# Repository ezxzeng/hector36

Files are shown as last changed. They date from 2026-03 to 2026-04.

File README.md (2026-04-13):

# Hector36
## A sub-100×100 mm split keyboard inspired by Totem, without the extra pinky key

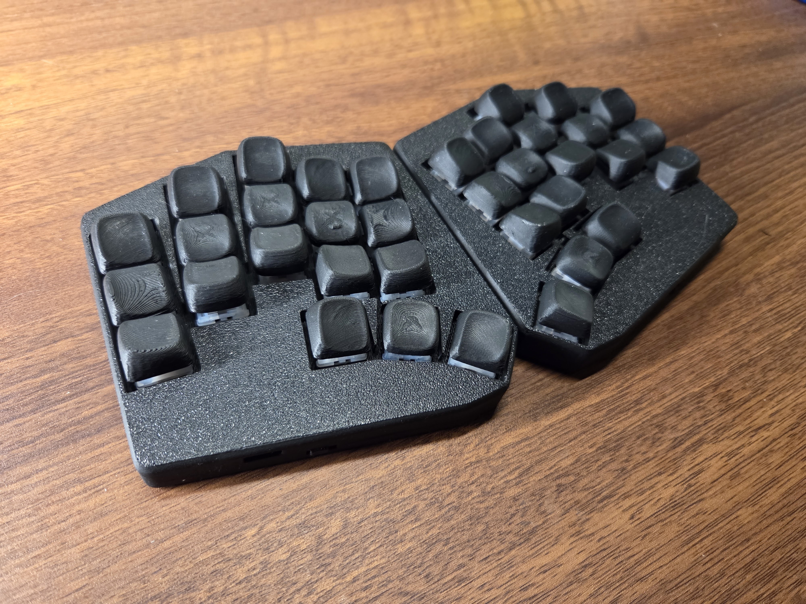
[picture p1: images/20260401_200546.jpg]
Hector36 assembled


left | right | outline
-|-|-
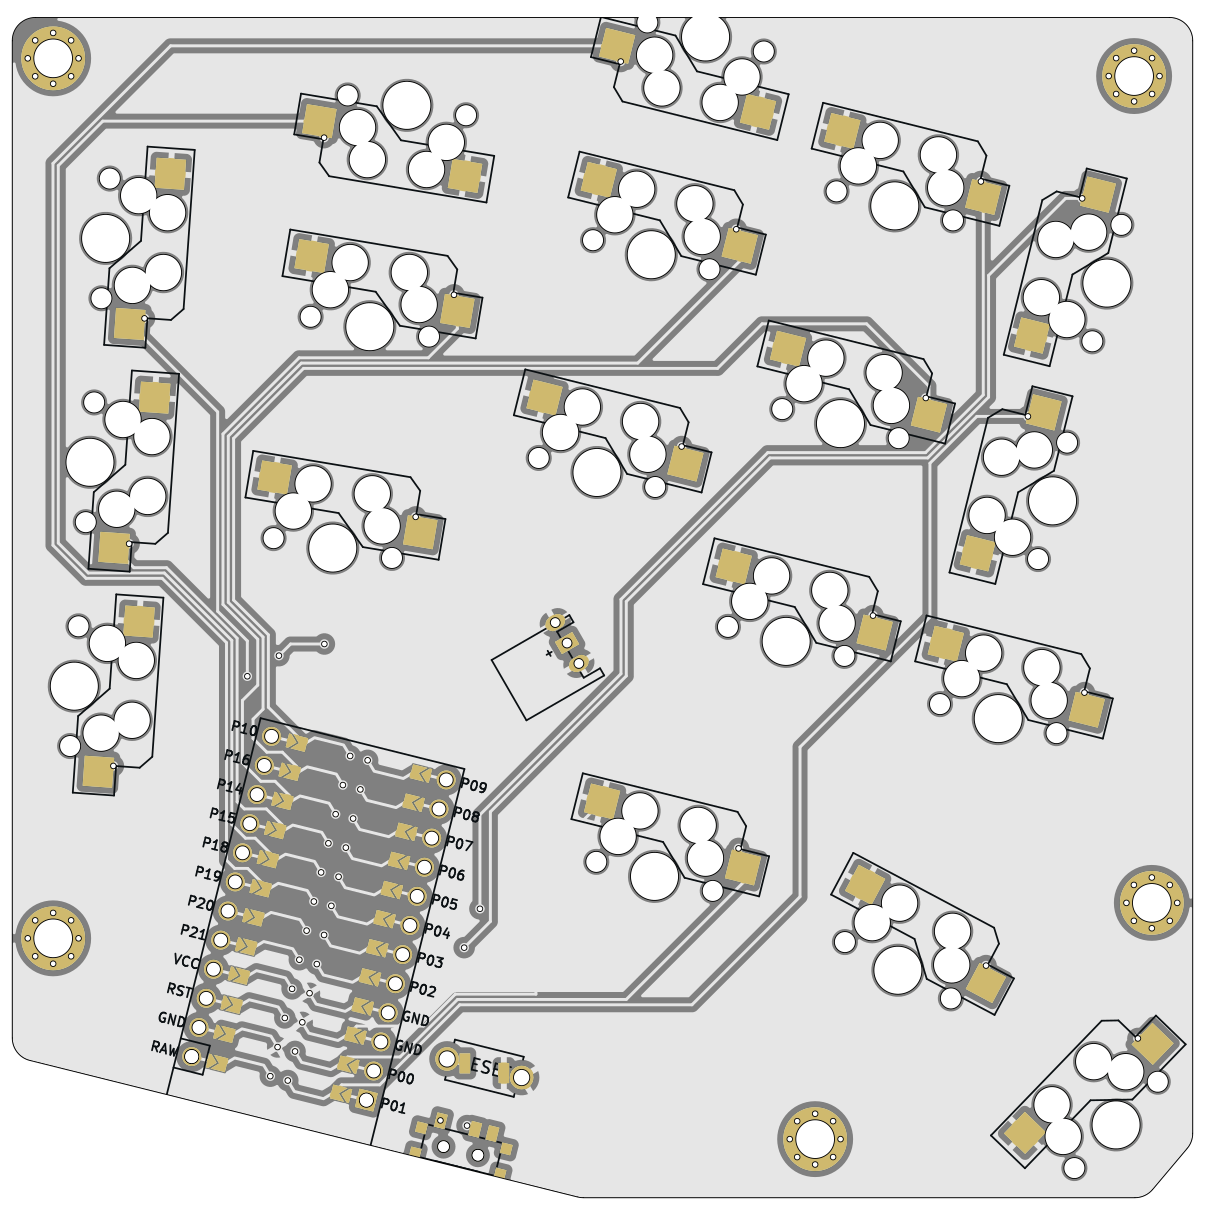
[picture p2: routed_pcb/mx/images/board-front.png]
left
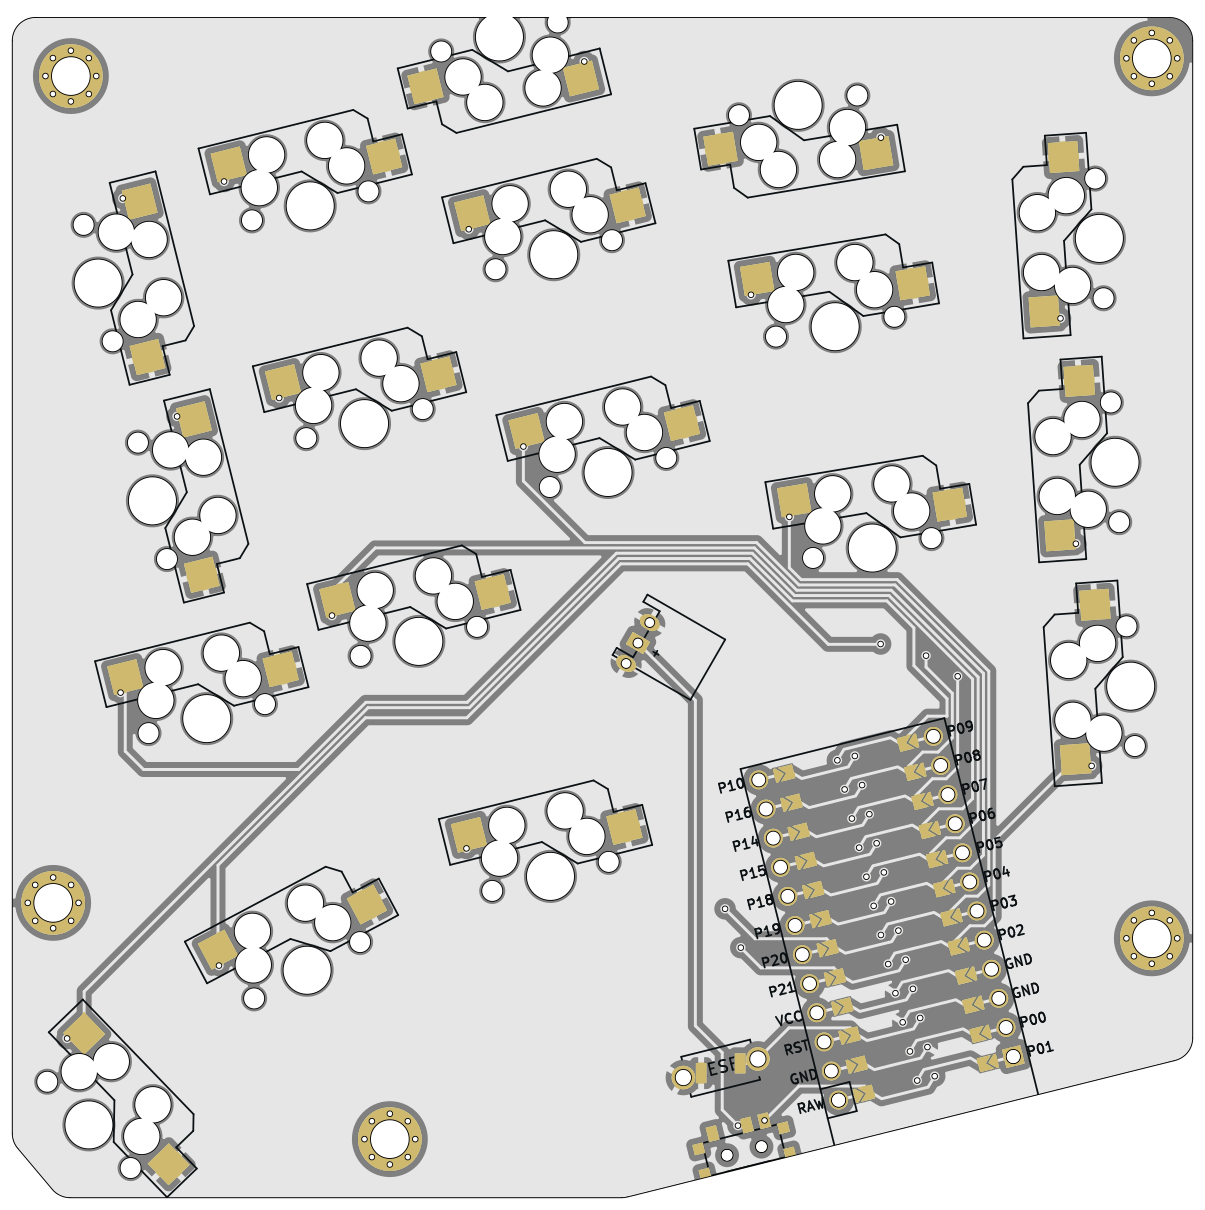
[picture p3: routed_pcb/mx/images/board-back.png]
right
 |  | outline

Hector36 is a 36-key split keyboard with a 5×3 layout and 3 thumb keys per half.  
It is designed to stay under **100 mm × 100 mm per PCB**, which makes fabrication much cheaper while still keeping a comfortable, aggressively staggered and splayed layout.

## Features
- Sub-100×100 mm PCB for low fabrication cost
- Split 36-key layout with 3 thumb keys per half
- Reversible PCB
- Diode-less design
- Programmatically generated with Ergogen
- hotswap sockets

## PCB variants

This repo currently contains several board variants:

| Version | Status | Folder | Buildguide |
|---|---|---|---|
| MX | Tested and working | [`routed_pcb/mx`](routed_pcb/mx) | [guide](routed_pcb/mx/README.md#Build-Guide)
| Choc with choc spacing | Fabricated, not yet received or tested | [`routed_pcb/choc_spacing`](routed_pcb/choc_spacing) | tbd
| Choc with mx spacing | Not routed | `routed_pcb/choc` | tbd
| Gateron low profile with mx spacing | Not routed | `routed_pcb/gateron_lp` | tbd

For PCB fabrication through JLCPCB or PCBWay, use the gerbers.zip file inside the corresponding version folder.

## Components

| Part | Qty | Estimated price | Notes |
| --- | --: | ---: | --- |
| PCB | 2 | $3.50 for 5 | |
| nice!nano or nRF52840 | 2 | $4 each for nRF52840 |  I'm using nRF52840 for cheaper cost |
| Reset switch | 2 | $3.40 for 100 | 3×6×2.5 mm, 2-pin, SMD push button |
| Power switch | 2 | $4 for 100 | 7-pin, MSK 12C02 |
| Battery | 2 | $15 for 2 | 301230, 3.7 V Li-Po |
| 2P ST PH2.0 right-angle socket | 2 | $2 for 100 | Optional |
| Hotswap socket |  36 | $10 for 70 | also depends on socket type |
| Switch |  36 | — | |
| Keycap |  36 | — | Some keycaps may need rotated orientation for the Choc version. |
| M3 heat-set insert | 8 | $3 for 50 | |
| M3 screw | 8 | $3 for 50 | |
| Rubber feet | 8 | $5 for 50 | |

note that estimated price is from a brief look at aliexpress, and might be higher than what you'll actually have to pay if you buy in higher quantities (especially for batteries)

optional: [socketing the controller](https://docs.splitkb.com/frequently-asked-questions/about-split-keyboards/microcontrollers/sockets), see [this guide](https://www.40percent.club/p/socketing-pro-micro.html) or [this guide](https://docs.splitkb.com/product-guides/aurora-series/build-guide/microcontrollers)

## Firmware
see [zmk module](https://github.com/ezxzeng/zmk-keyboards-hector36)

## Inspiration

- [bgkeeb](https://github.com/sadekbaroudi/bgkeeb)
  - keyboard pcbs under 100mm x 100mm are cheap
- [cheapis](https://github.com/dotleon/cheapis) 
  - sweeps can be rotated for more room and length between the thumb cluster and rest of the keys and still fit within 100mm x 100mm
- [samoklava](https://github.com/soundmonster/samoklava) and [ergogen](https://ergogen.cache.works/) to get keyboard layouts programatically 
- [sweep](https://github.com/davidphilipbarr/Sweep) and [swweeep](https://github.com/sadekbaroudi/sweep36) for form factor and diode-less design
- [totem](https://github.com/GEIGEIGEIST/totem) and [KLOR](https://github.com/GEIGEIGEIST/KLOR)
  - keys layout
  - sandwich case looks really slick and clean, and can also hide the controller parts that will be located under the palm

## Other considerations
- this design does not support LEDs or displays
- [samoklava's](https://github.com/soundmonster/samoklava) auto routing does not really work here
- some keycaps might need to be rotated 90 degrees

## Rendering and generation

### Ergogen:
```bash
ergogen .
```
### Case:
printables: https://www.printables.com/model/1659997-case-for-hector36

onshape [link](https://cad.onshape.com/documents/dab7ead69061981322a5fa82/w/eeec2b07408bf6c3576b55db/e/49101eb28d1b1828dfaa91ca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)

### Get board image renderings:
```bash
export pcb_type="mx"

docker run -v $(pwd):/kikit --entrypoint pcbdraw yaqwsx/kikit:v1.3.0-v7  plot --style style.json routed_pcb/$pcb_type/board.kicad_pcb routed_pcb/$pcb_type/images/board-front.png

docker run -v $(pwd):/kikit --entrypoint pcbdraw yaqwsx/kikit:v1.3.0-v7  plot --style style.json --side back routed_pcb/$pcb_type/board.kicad_pcb routed_pcb/$pcb_type/images/board-back.png
```

## Showcase



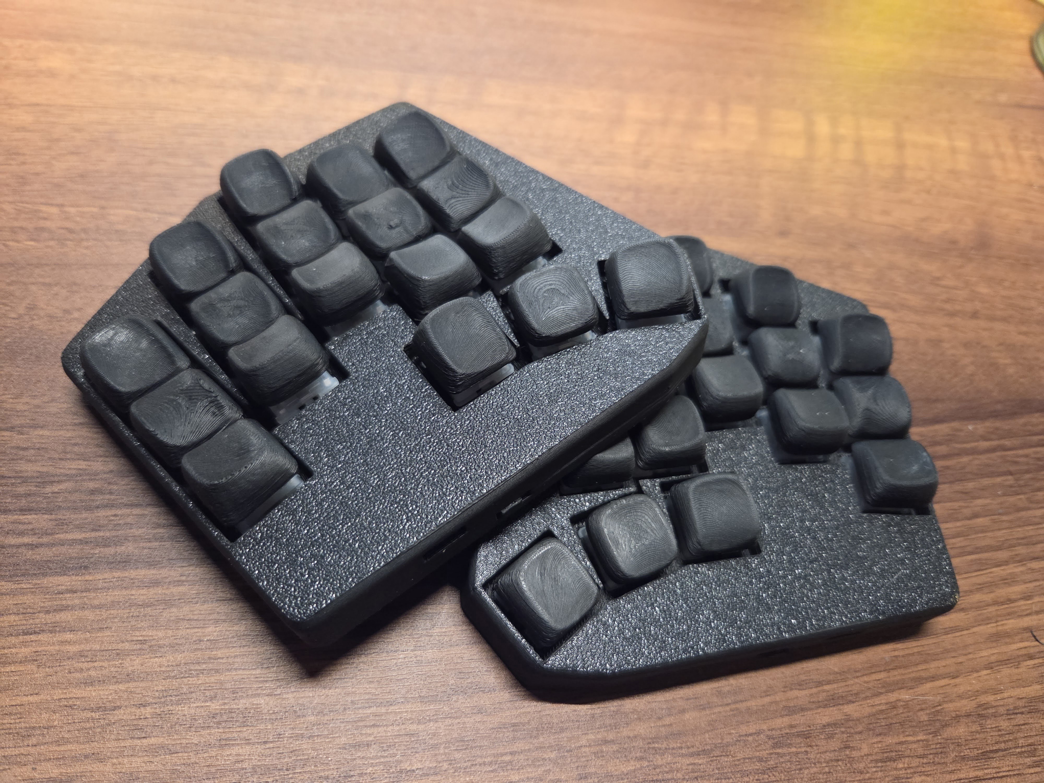
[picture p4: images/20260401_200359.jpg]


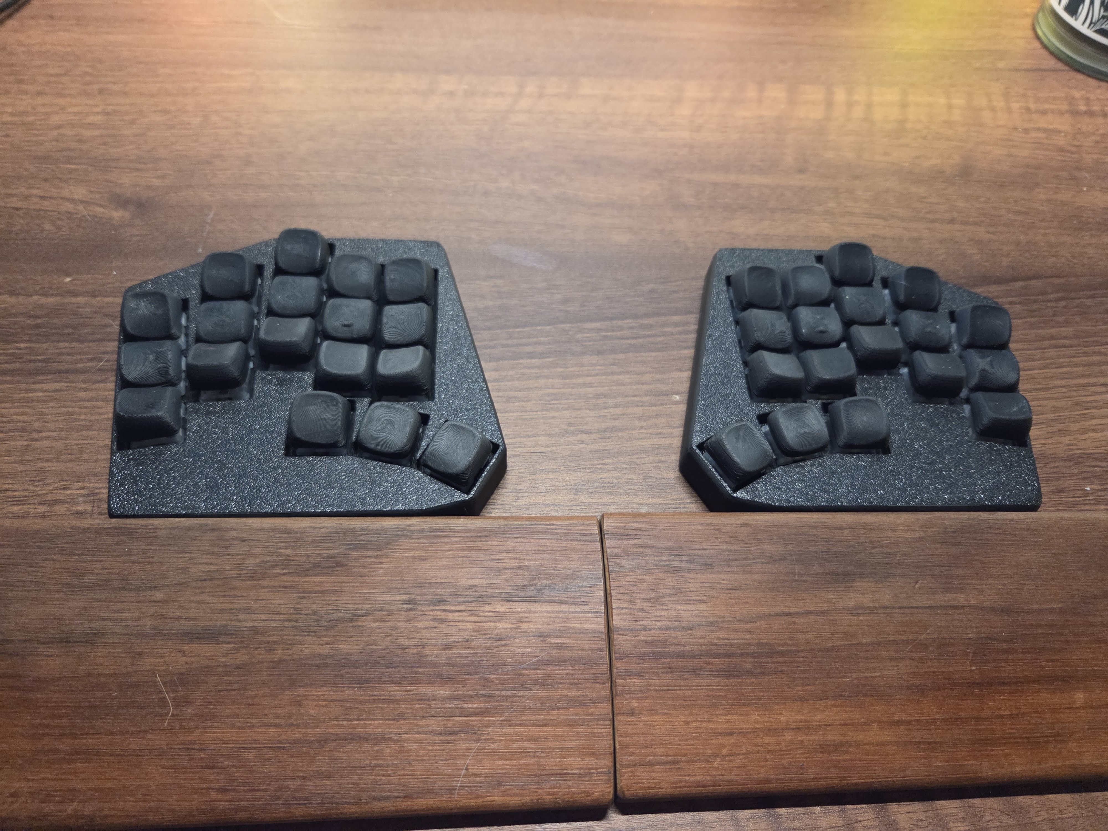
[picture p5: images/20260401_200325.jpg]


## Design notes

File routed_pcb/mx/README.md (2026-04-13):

left | right | outline
-|-|-
left | right | outline

# Build Guide

## 1. PCB
1. Take 2 pcbs and flip them to the **back** side
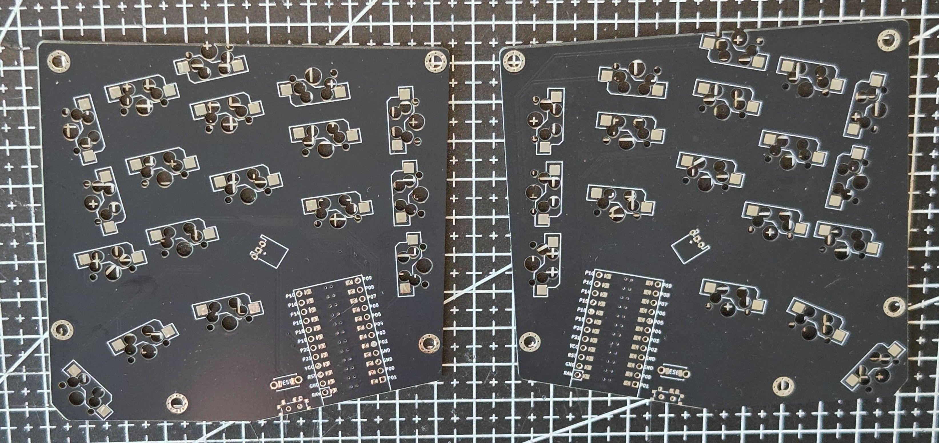
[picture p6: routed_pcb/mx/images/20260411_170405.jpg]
flip to back


1. Solder the jumper pads for the controller so that the two sides of the pads can be connected together.
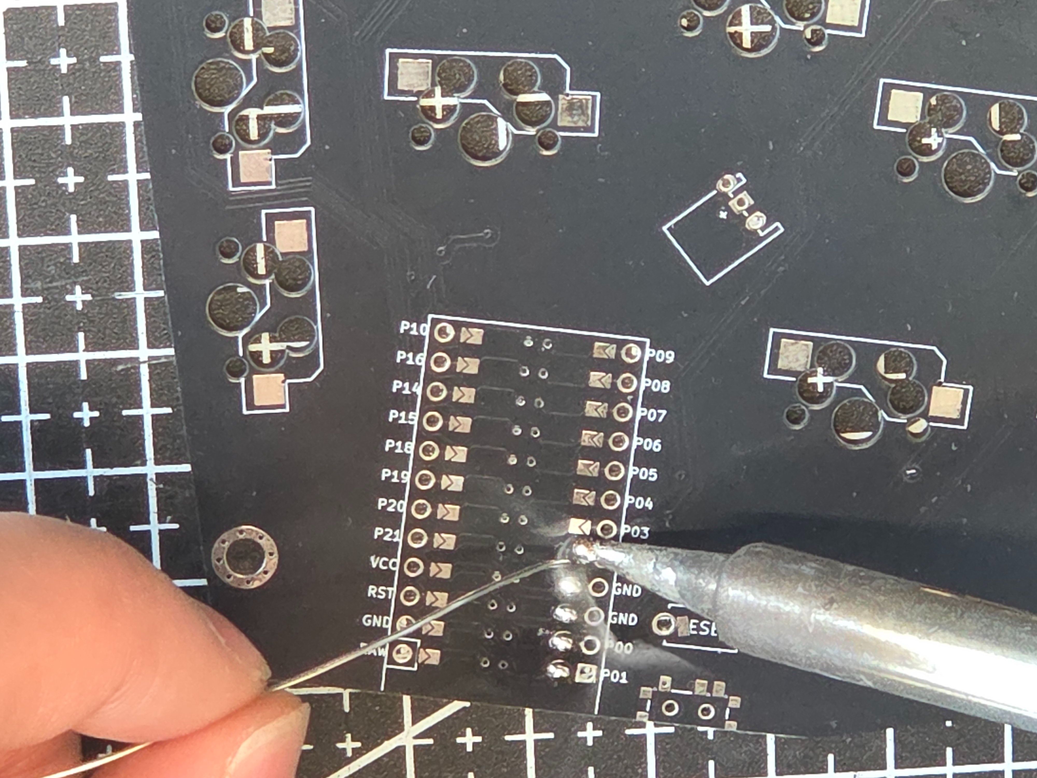
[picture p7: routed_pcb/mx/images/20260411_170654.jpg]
solder jumper pads


1. Still on the back side, put solder on the pads for the hotswap sockets
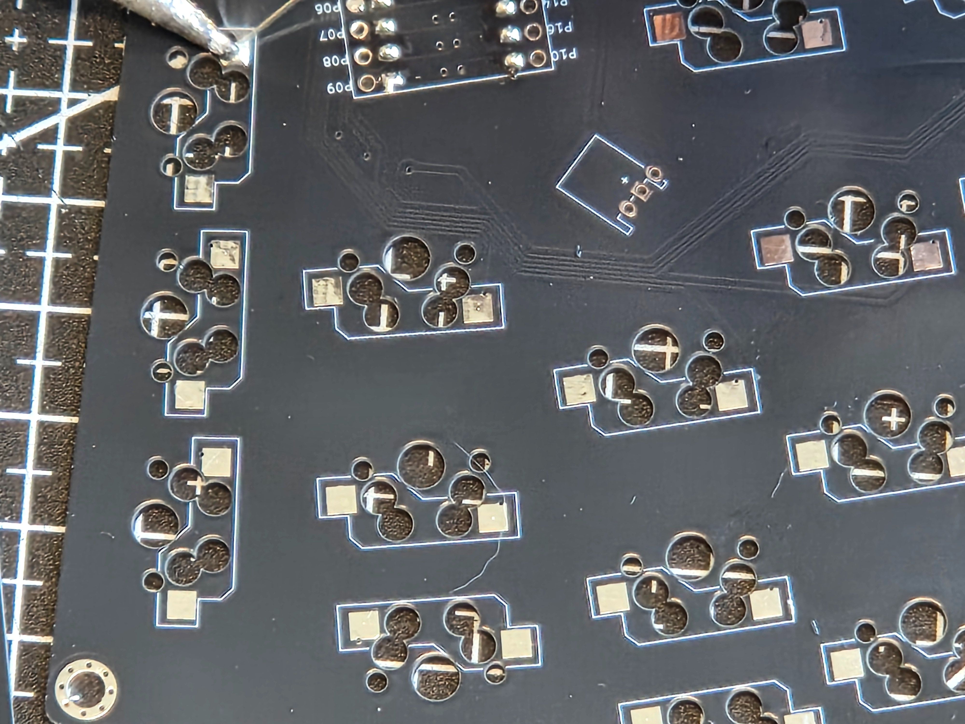
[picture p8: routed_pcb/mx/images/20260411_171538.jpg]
hotswap sockets


1. Melt the solder and press the hotswap sockets down, one side at a time. Use tweezers if that helps.
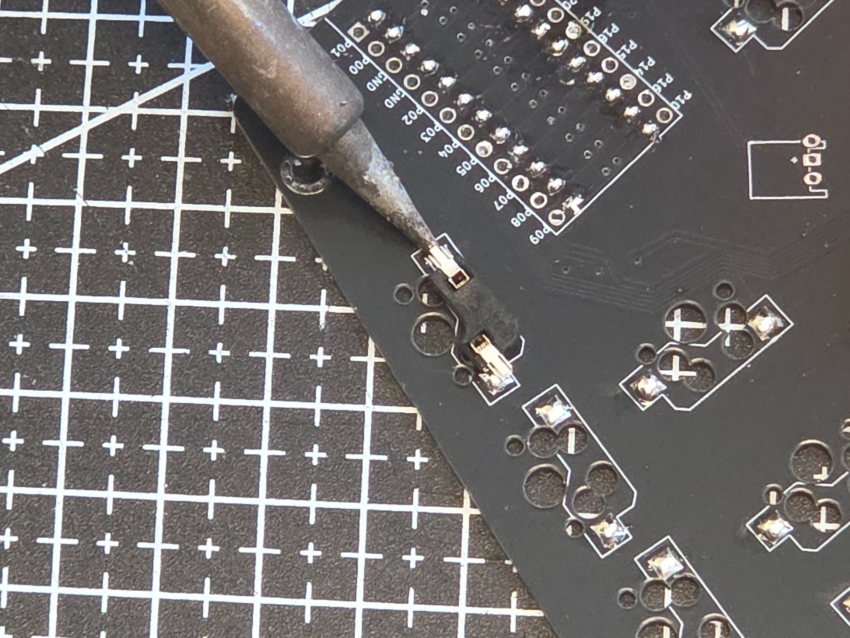
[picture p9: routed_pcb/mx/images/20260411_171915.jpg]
hotswap sockets 3


1. Still on the back side, put down the reset switch and solder it in. Depending on what switch you're using, it might help to bend the pins a bit down so it'll go inside the hole.
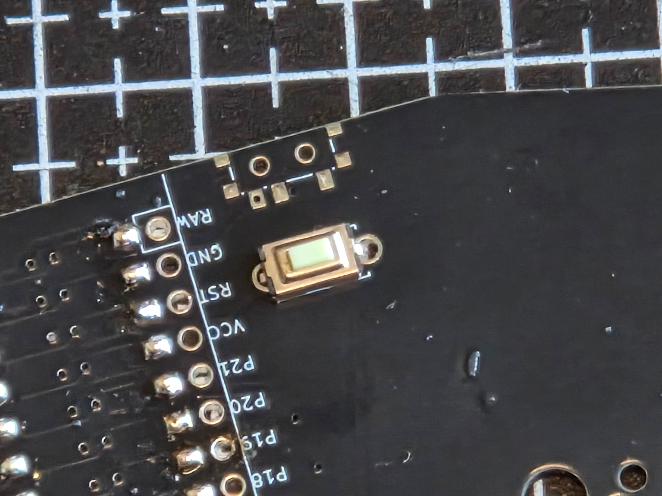
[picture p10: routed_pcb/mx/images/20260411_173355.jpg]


1. Flip over to the **front** side. Place the on/off switch and solder it in
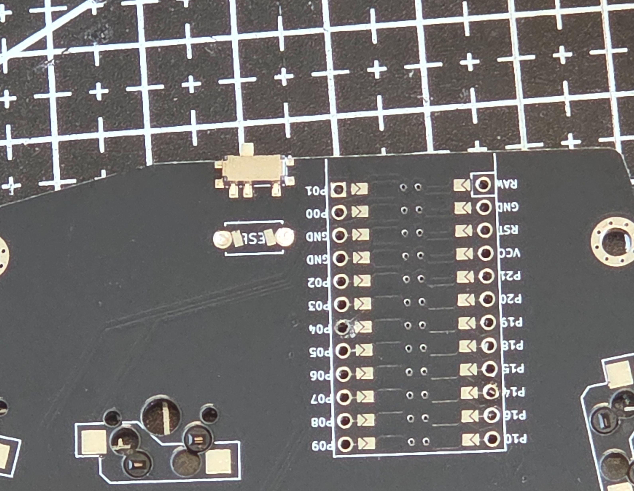
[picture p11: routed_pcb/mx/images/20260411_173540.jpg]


1. (Optional) align the JST connectors with the + sign. This may be different from the rectangle drawn on the pcb depending on where you order the right angle JST connectors from, or how the male connector on the battery looks. What's important is that the red wire aligns with the + sign. 
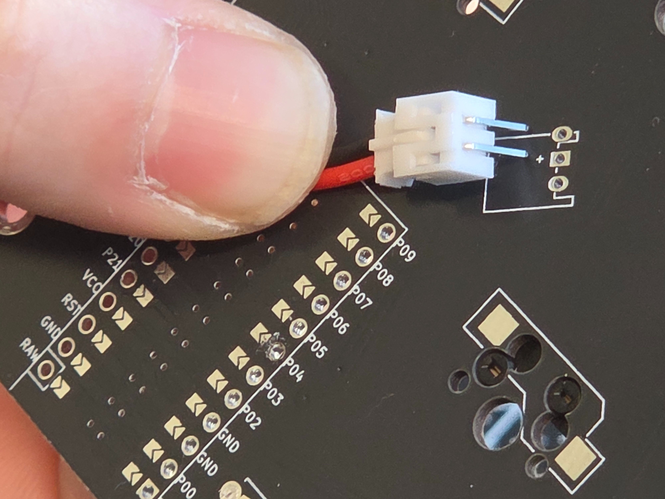
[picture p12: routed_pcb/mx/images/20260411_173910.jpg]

1. Solder the JST connector from the back. Alternatively, solder the battery wires directly.
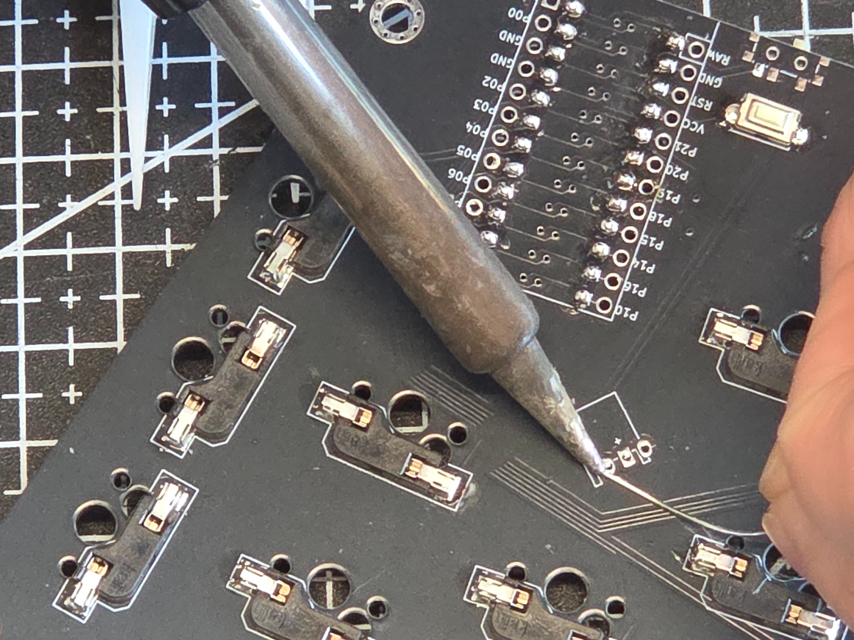
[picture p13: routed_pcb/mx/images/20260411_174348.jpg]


1. Back on the front side, place the controller **with the components side down**. The markings for which pin is what aligns on the **back** side, not the front. The two pins closest to the USBC port are **empty** and not used. Those are for Battery + and -, which are the same thing as RAW and GND.
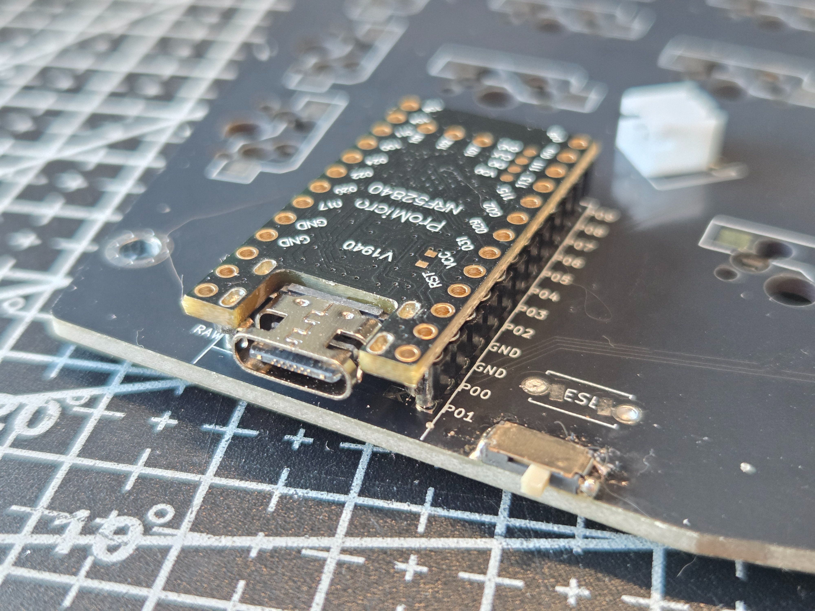
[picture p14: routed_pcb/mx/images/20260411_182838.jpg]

optionally, but highly recommended, follow [this](https://www.40percent.club/p/socketing-pro-micro.html) or [this alternative](https://docs.splitkb.com/product-guides/aurora-series/build-guide/microcontrollers) guide on how to socket the controller (see [here](https://docs.splitkb.com/frequently-asked-questions/about-split-keyboards/microcontrollers/sockets) for why you would want to).

1.  The finished PCB should look like this, with the battery slotted under the controller.
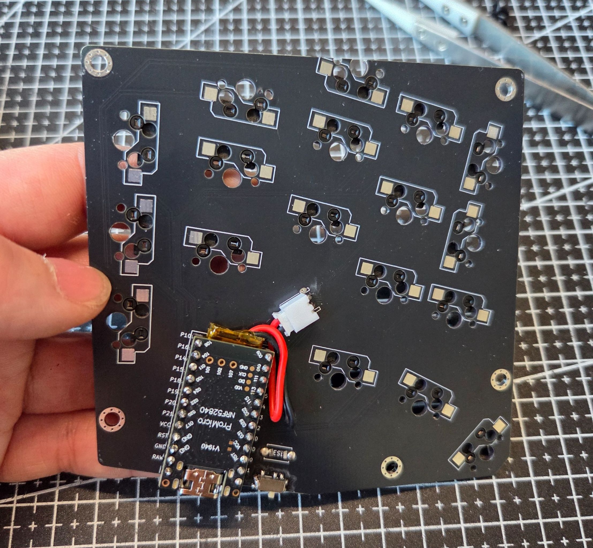
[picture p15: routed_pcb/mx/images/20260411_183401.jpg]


1.  Alternatively, if the battery does not fit under the controller, you can also put it on the side like this:
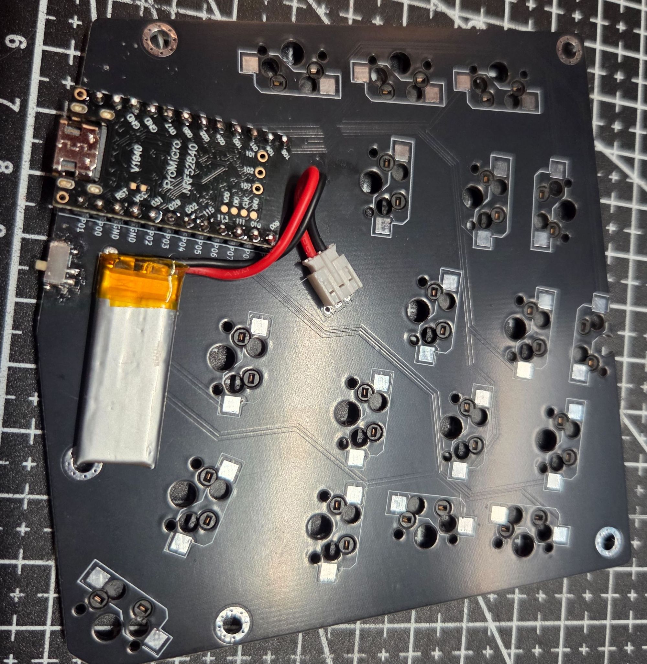
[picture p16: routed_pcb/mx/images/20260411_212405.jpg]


## 2. Case

Before printing, measure the distance from the top of the usbc port to the bottom of the pcb:
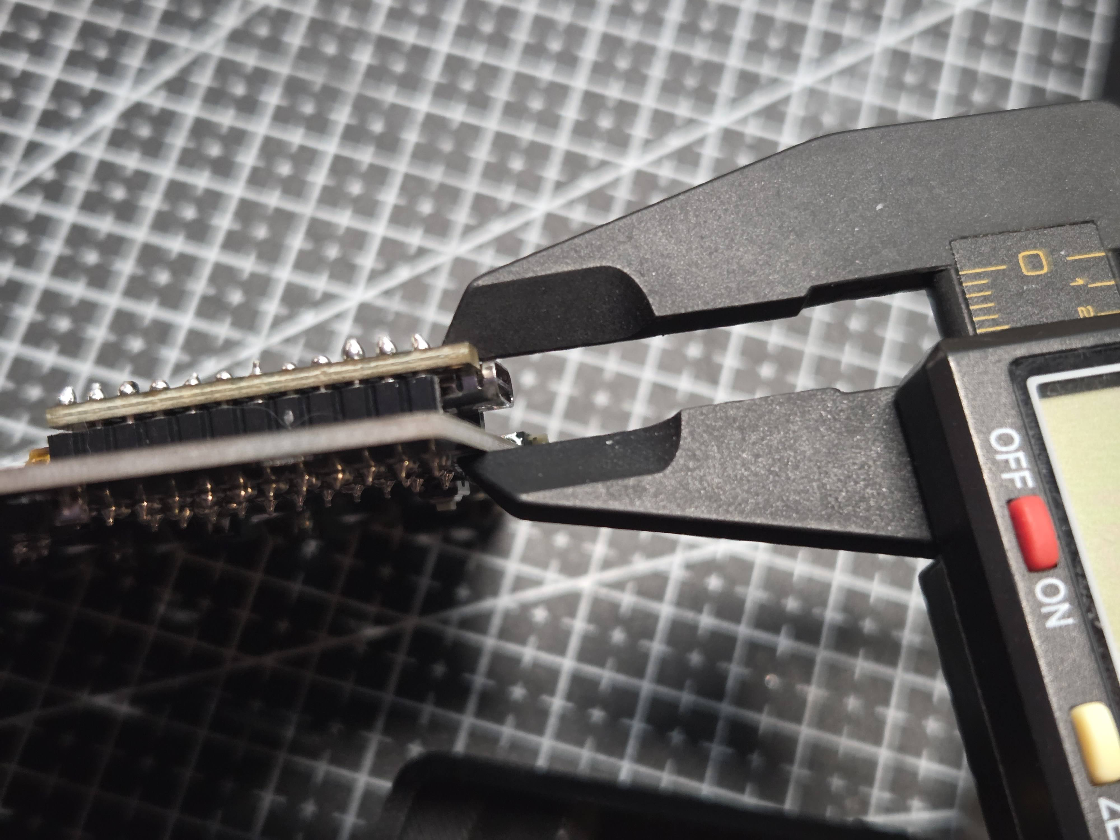
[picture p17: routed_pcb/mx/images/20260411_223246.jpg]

If this value is between 7.2mm and 8.2mm, then go ahead and use the STL files available on [printables](https://www.printables.com/model/1659997-case-for-hector36). Otherwise, you can copy and edit the [onshape file](https://cad.onshape.com/documents/dab7ead69061981322a5fa82/w/eeec2b07408bf6c3576b55db/e/49101eb28d1b1828dfaa91ca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). Simply modify the `bottom_pcb_to_usbc` variable at the top of the variable table.

1. Print the top half face down, and enable supports:
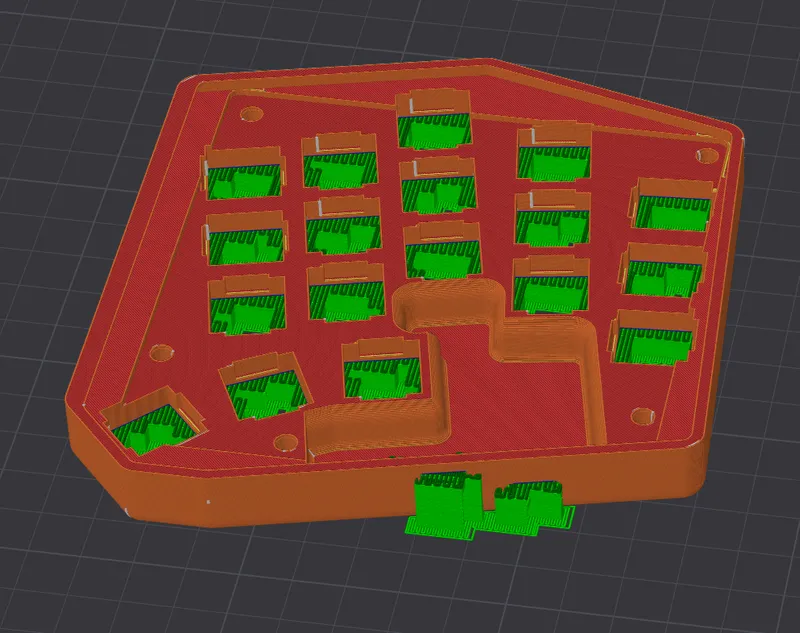
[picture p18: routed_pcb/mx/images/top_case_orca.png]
top_case_orca

1. disable support for the bottom part.
2. remove the support for the top half:
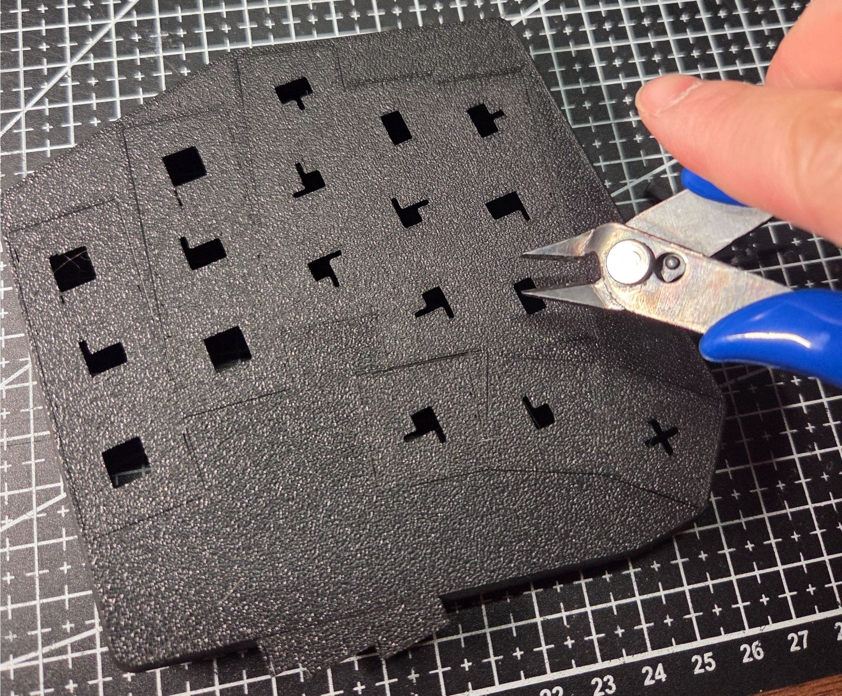
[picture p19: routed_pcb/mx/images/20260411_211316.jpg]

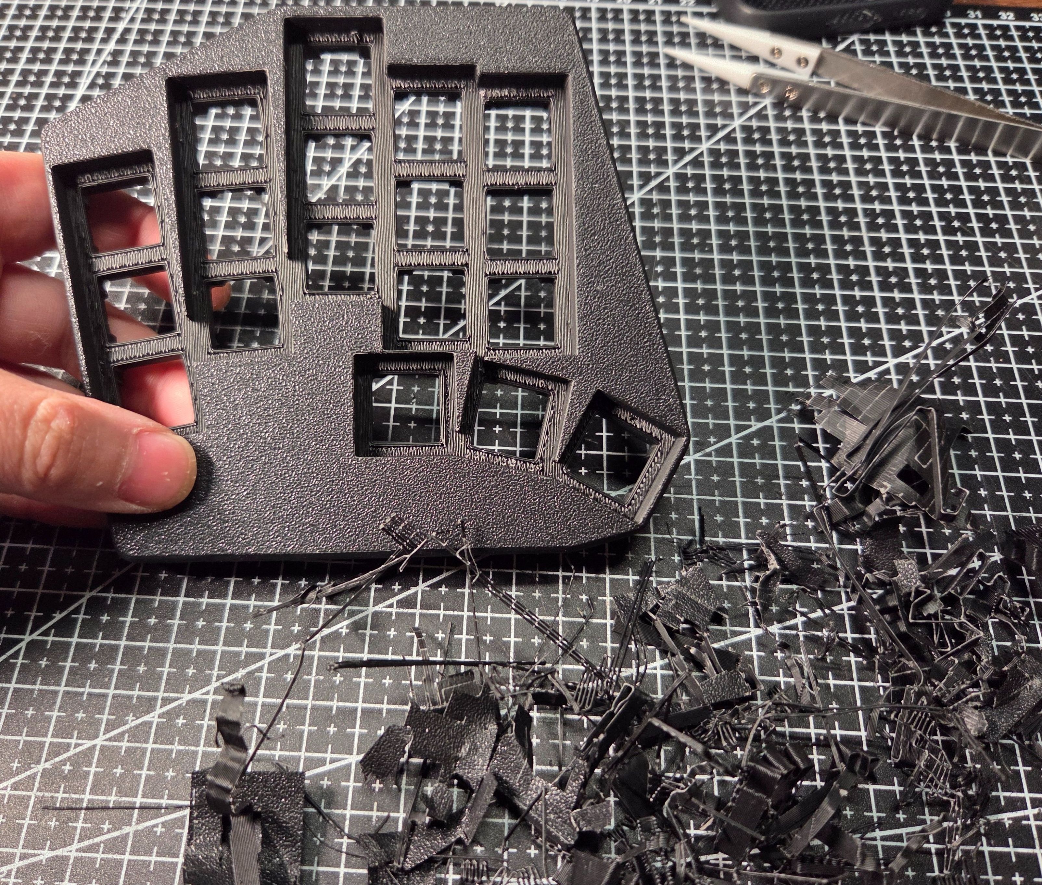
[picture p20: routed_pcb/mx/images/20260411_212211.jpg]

1. put in the M3 heat set inserts:
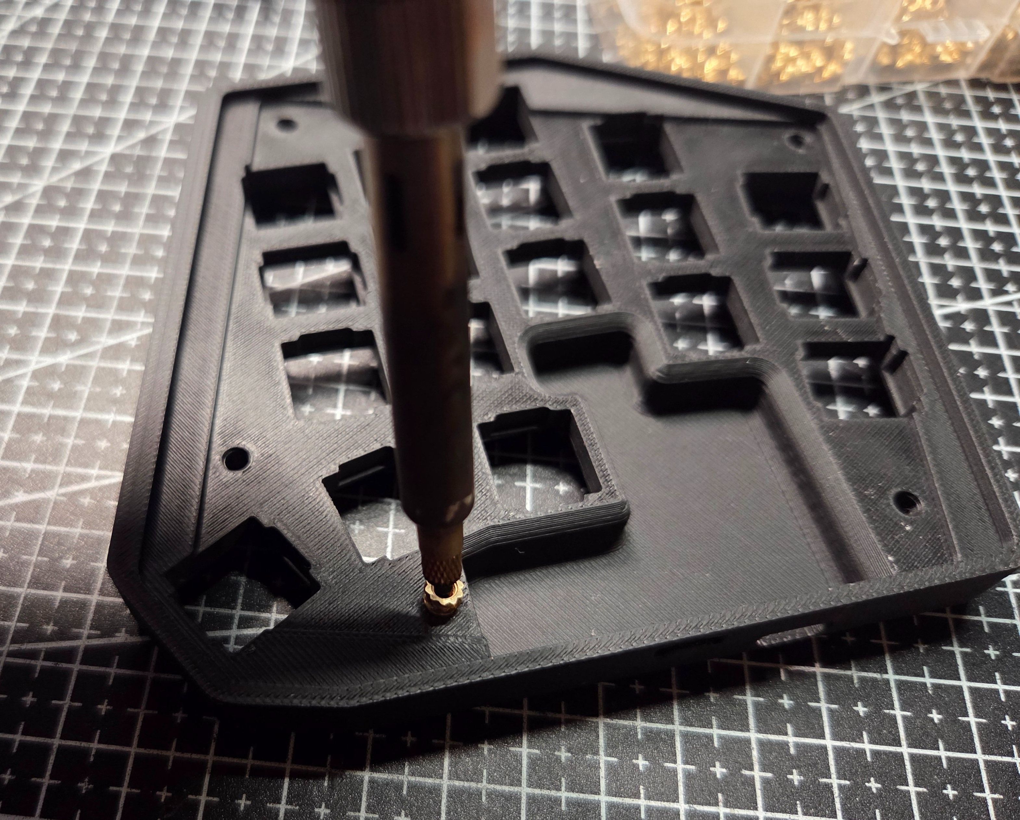
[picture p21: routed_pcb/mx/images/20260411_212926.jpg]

1. put in the switch extender in the orientation shown below
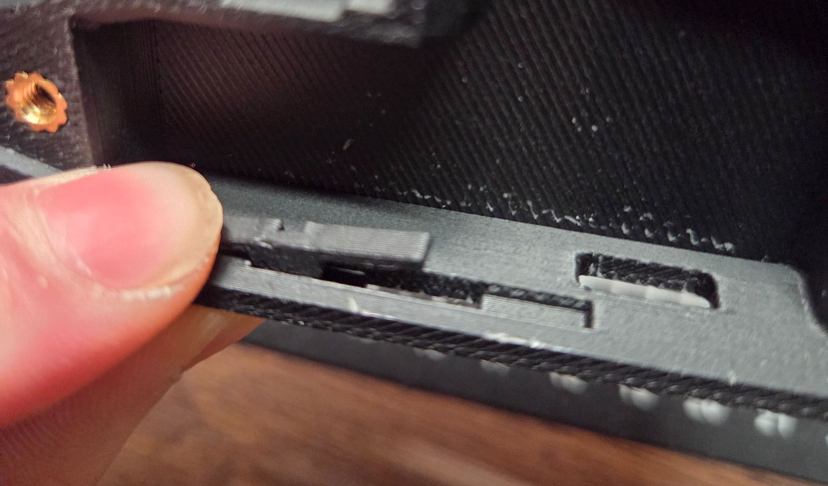
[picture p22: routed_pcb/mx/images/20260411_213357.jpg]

1. put everything together and we're done!
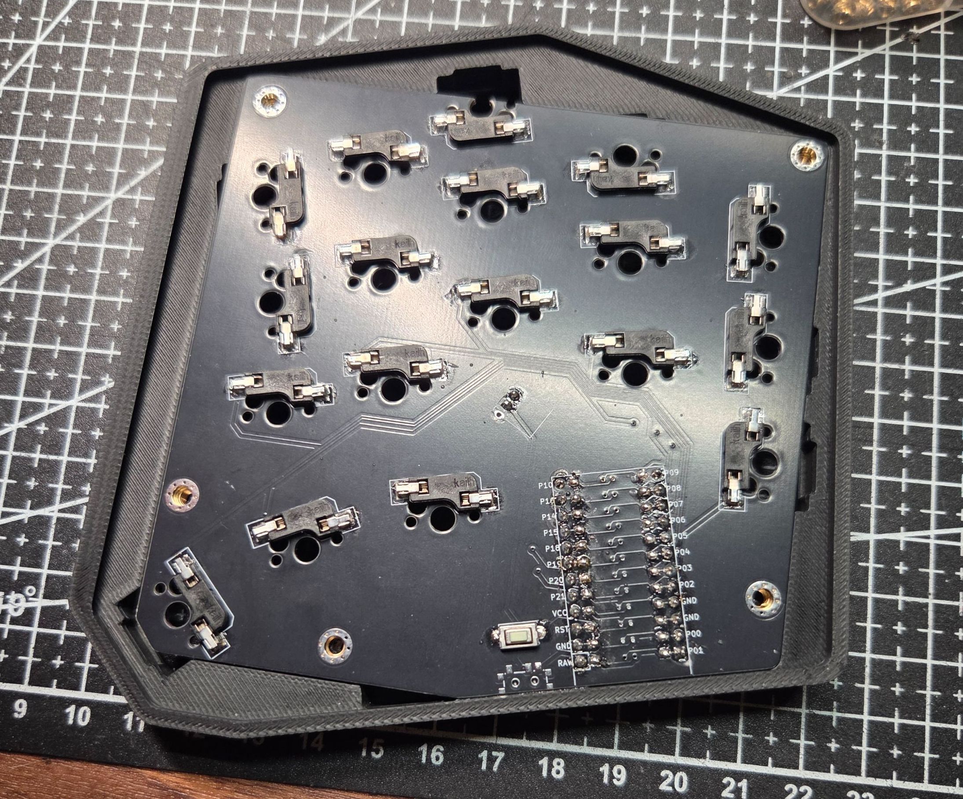
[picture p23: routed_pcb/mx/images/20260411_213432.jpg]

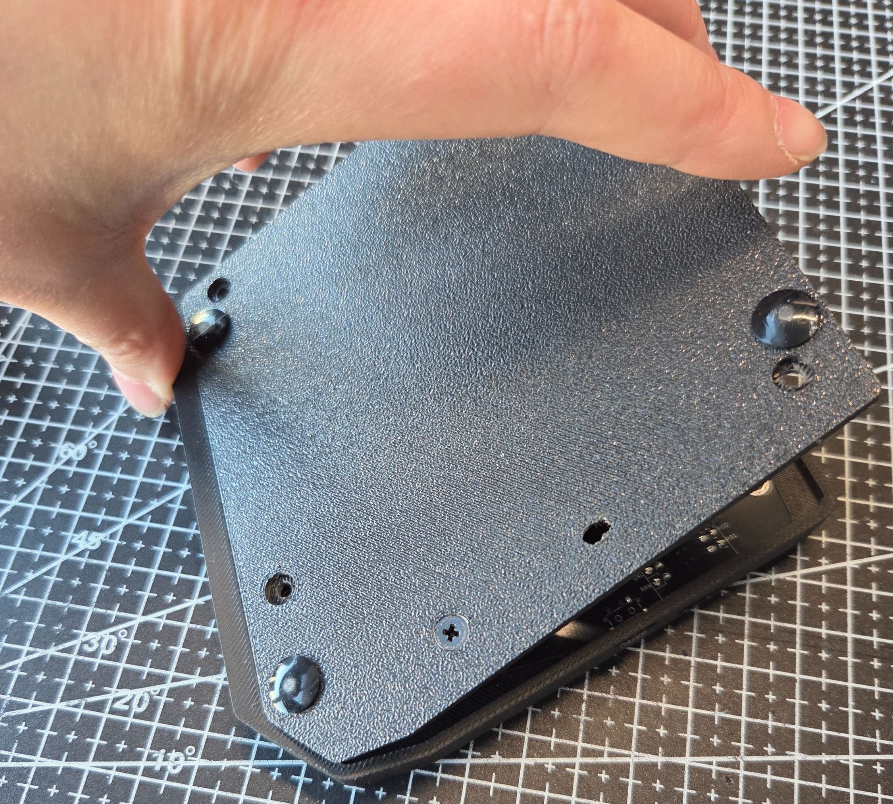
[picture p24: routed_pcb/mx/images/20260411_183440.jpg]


## Firmware
see [zmk module](https://github.com/ezxzeng/zmk-keyboards-hector36)

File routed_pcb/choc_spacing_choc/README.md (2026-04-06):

left | right | outline
-|-|-
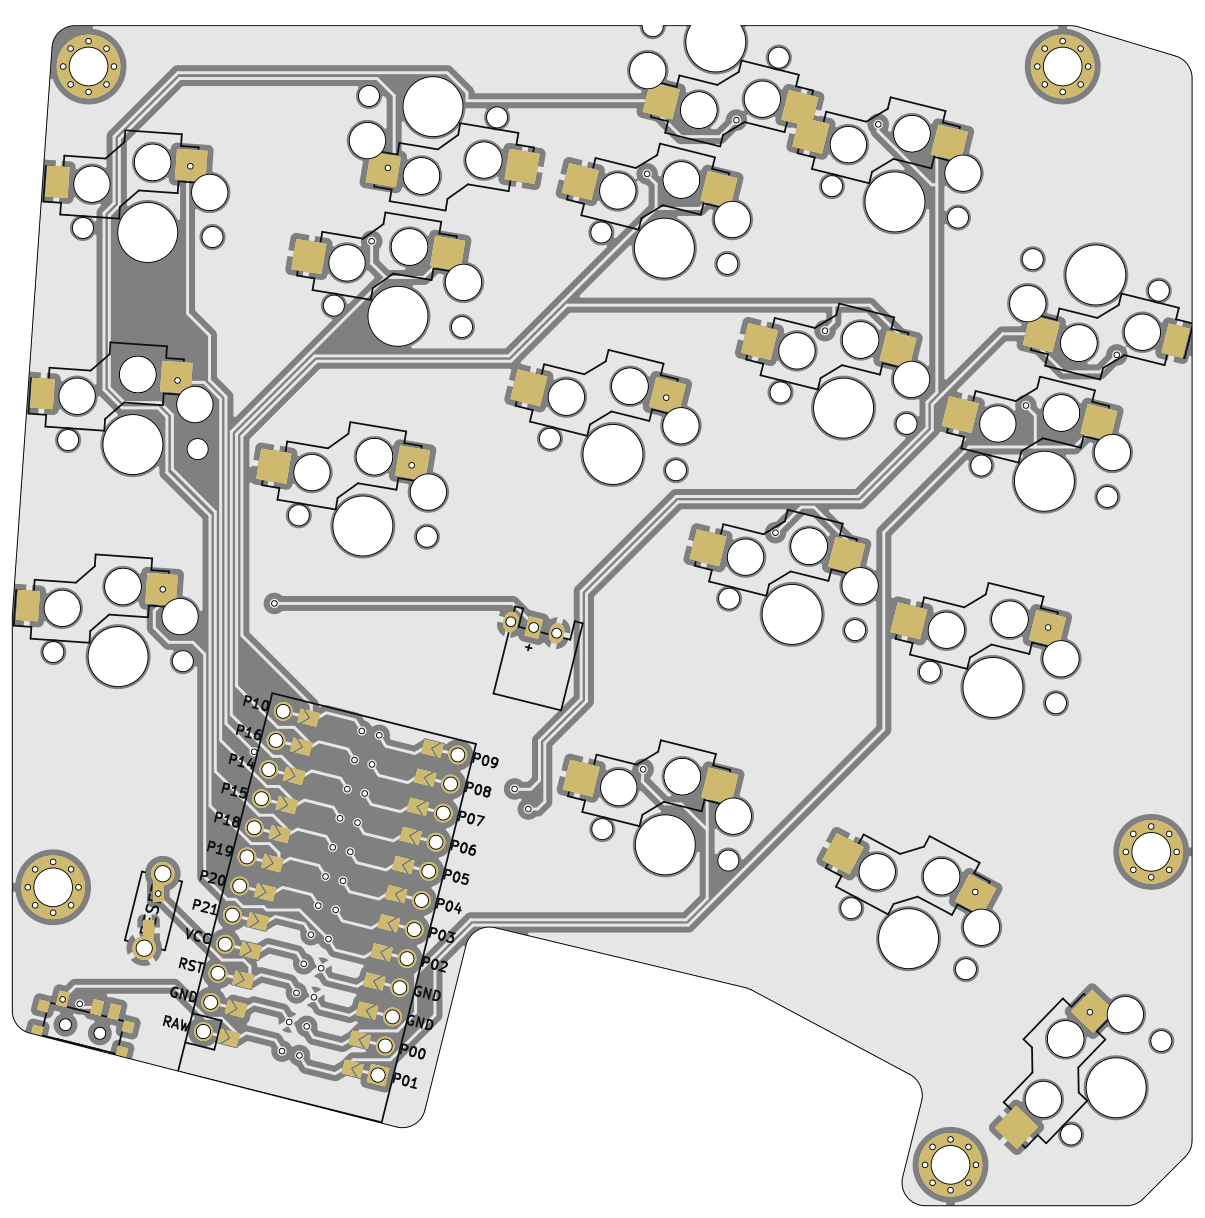
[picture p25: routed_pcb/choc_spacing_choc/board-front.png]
left
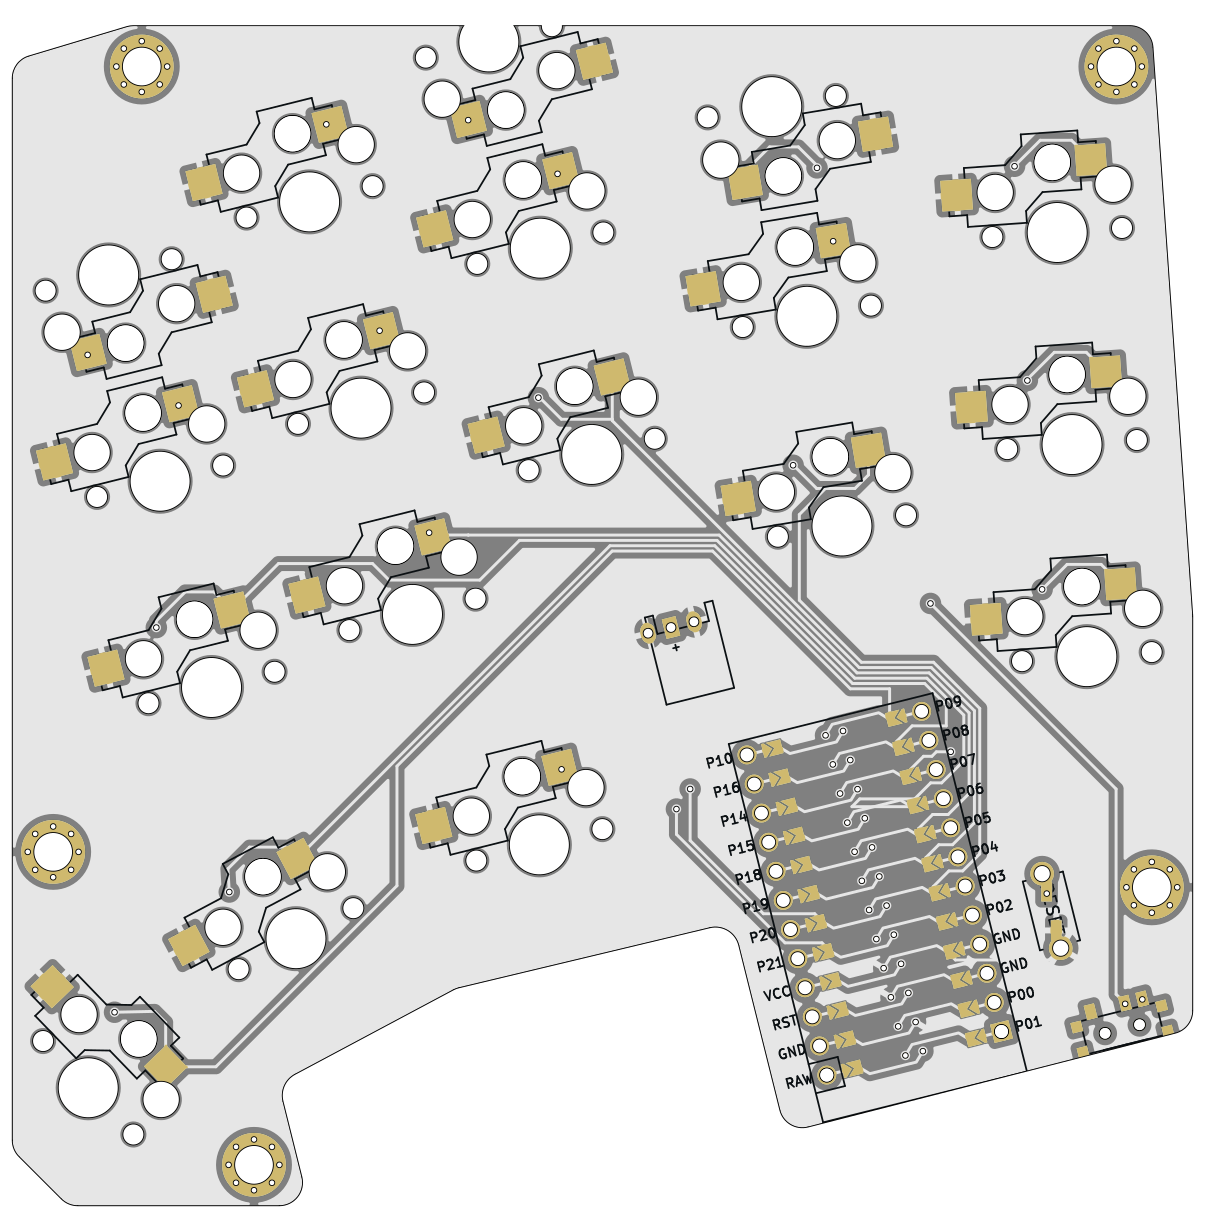
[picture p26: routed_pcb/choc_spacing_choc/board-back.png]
right
 |  | outline

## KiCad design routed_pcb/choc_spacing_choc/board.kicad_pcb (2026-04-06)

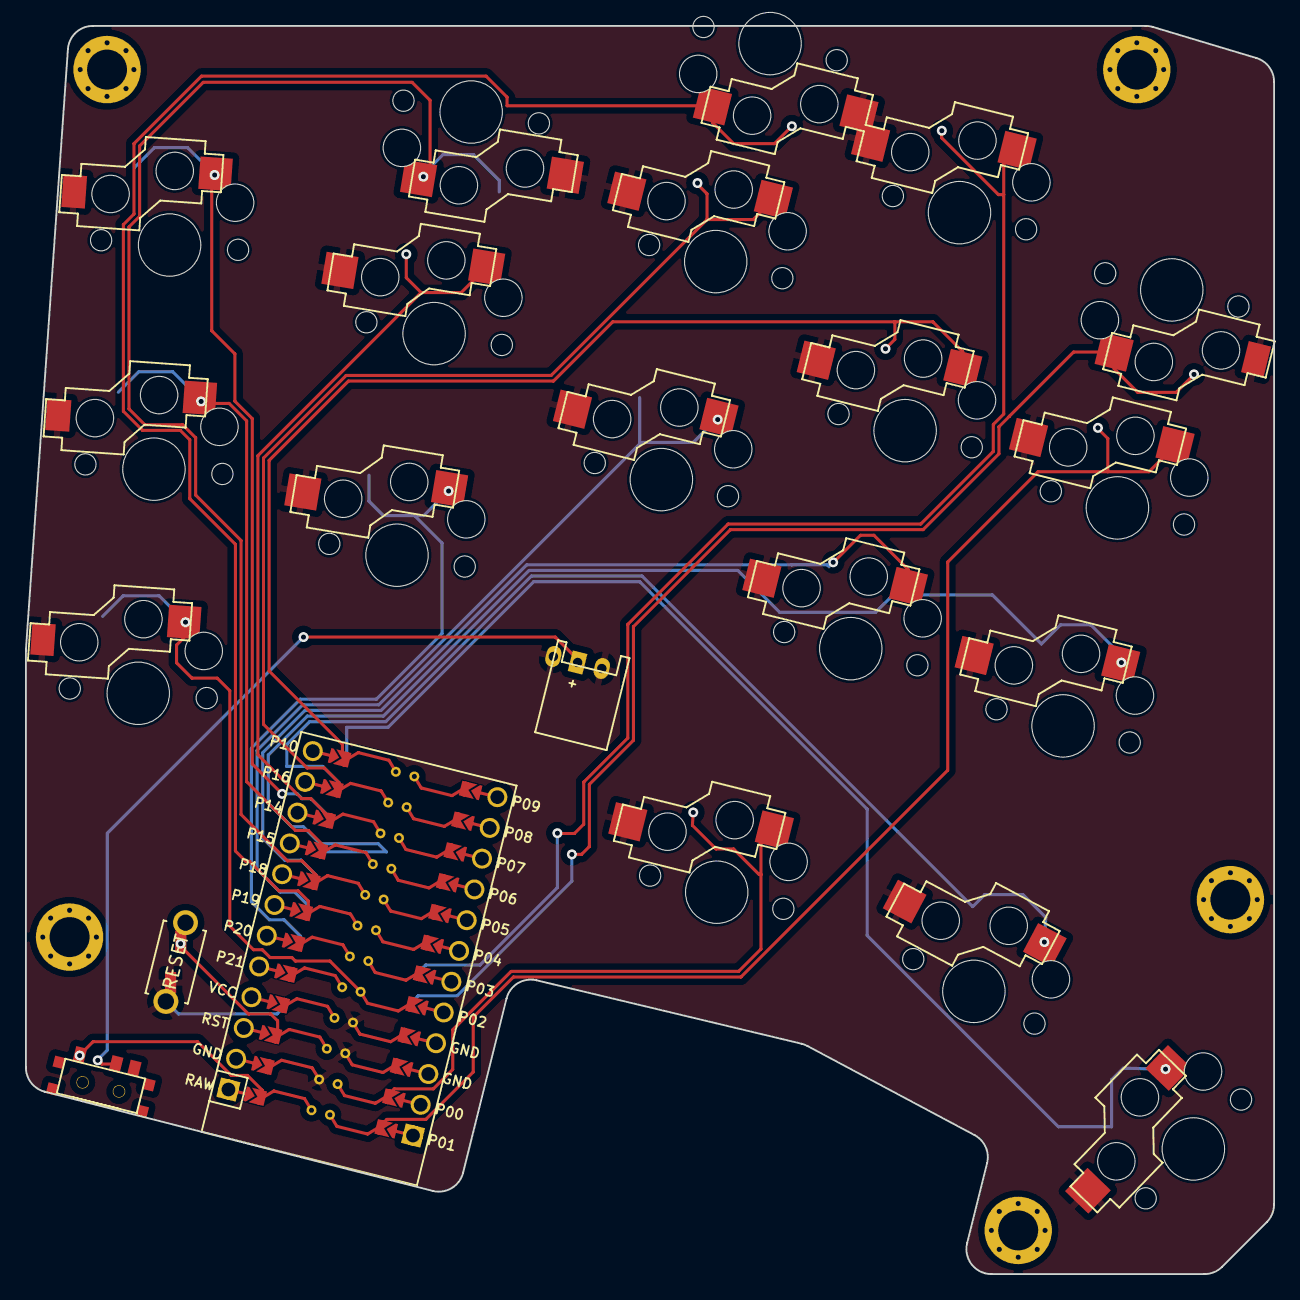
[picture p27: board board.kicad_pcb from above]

Board: 2 copper layers, 100.0 x 100.0 mm, 28 parts (0 on the bottom side), 22 nets.

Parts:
B1: ResetSW
B2: SW_SPST_B3U-1000P
HOLE1, HOLE2, HOLE3, HOLE4, HOLE5: MountingHole_3.2mm_Pad_Via
JST1: JST_PH_S2B-PH-K_02x2.00mm_Angled
MCU1: ProMicro
SW1, SW2, SW3, SW4, SW5, SW6, SW7, SW8, SW9, SW10, SW11, SW12, SW13, SW14, SW15, SW16, SW17, SW18: key-switches
T1: SPDT_C128955

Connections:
Bplus: JST1.1, T1.2
GND: B1.2, B2.2, JST1.2, MCU1.2, MCU1.21, MCU1.22, SW1.2, SW2.2, SW3.2, SW4.2, SW5.2, SW6.2, SW7.2, SW8.2, SW9.2, SW10.2, SW11.2, SW12.2, SW13.2, SW14.2, SW15.2, SW16.2, SW17.2, SW18.2
RAW: MCU1.1, T1.1
RST: B1.1, B2.1, MCU1.3
matrix_index_bottom: MCU1.17, SW10.1
matrix_index_home: MCU1.12, SW11.1
matrix_index_top: MCU1.6, SW12.1
matrix_inner_bottom: MCU1.16, SW13.1
matrix_inner_home: MCU1.24, SW14.1
matrix_inner_top: MCU1.5, SW15.1
matrix_middle_bottom: MCU1.18, SW7.1
matrix_middle_home: MCU1.11, SW8.1
matrix_middle_top: MCU1.7, SW9.1
matrix_pinky_bottom: MCU1.20, SW1.1
matrix_pinky_home: MCU1.9, SW2.1
matrix_pinky_top: MCU1.15, SW3.1
matrix_ring_bottom: MCU1.19, SW4.1
matrix_ring_home: MCU1.10, SW5.1
matrix_ring_top: MCU1.8, SW6.1
thumb_inner: MCU1.23, SW16.1
thumb_reachy: MCU1.13, SW18.1
thumb_tucky: MCU1.14, SW17.1

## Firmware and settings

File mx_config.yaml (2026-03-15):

units:
  mx:                 1
  choc:               0
  gateron_lp:         0

  mx_spacing:         1
  millmax_diameter:   1.6
  mx_hotswap:         1
  mx_reverse:         1
  mx_pth:             0
  mx_rev_pad:         1
  mx_neg_y:           1
  gateron_lp_hotswap: 1
  gateron_lp_reverse: 1
  gateron_lp_pth:     0
  gateron_lp_rev_pad: 1
  gateron_lp_neg_y:   1
  choc_hotswap:       1
  choc_millmax:       0
  choc_reverse:       1
  choc_pth:           0
  choc_neg_y:         1
  keycaps:            1
  center_x: 133.5
  center_y: -99.8
  kx: 19
  ky: 19
  px: kx + 1.2
  py: ky + 1.2
  thumb_size: 1
  pinky_splay: -5.5
  ring_splay: -4.5
  main_rot: -4
  tot_rot: pinky_splay+ring_splay+main_rot

  mcu_x: -24
  mcu_y: -26.3
  mcu_rot: 90+tot_rot
  reset_x: -10
  reset_y: -39
  reset_rot: tot_rot + 180
  power_x: -12
  power_y: -46
  power_rot: tot_rot+180
  jst_x: -3
  jst_y: -3
  jst_rot: -60
  bottom_left_pcb_cut: 12

  case_left_offset: 7.5
  case_top_offset: 11.5
  case_right_offset: 8
  case_left_to_mid_finger_top: 54
  case_tol: 0.2
  bottom_left_case_cut: bottom_left_pcb_cut + abs(case_left_offset*tan((tot_rot)*pi/180))-case_tol
  left_case_x_travel: abs((100-bottom_left_case_cut)*tan((main_rot)*pi/180))
  top_left_case_offset: case_left_offset - left_case_x_travel
  mid_finger_top_to_case_right_x: case_right_offset+ top_left_case_offset +100-case_left_to_mid_finger_top
  mid_finger_top_to_case_right_y: -1*abs(mid_finger_top_to_case_right_x * tan((tot_rot)*pi/180))
  case_bottom_offset: 8
  case_thumb_x: -14
  case_thumb_y: -14.5

  mounting_0_x: center_x-46.5
  mounting_0_y: center_y+46.5
  mounting_1_x: center_x+45
  mounting_1_y: center_y+45
  mounting_2_x: center_x+46.5
  mounting_2_y: center_y-25
  mounting_3_x: center_x+18
  mounting_3_y: center_y-45
  mounting_4_x: center_x-46.5
  mounting_4_y: center_y-28

points:
  zones:
    matrix:
      # Fix placement on KiCAD sheet.
      anchor.shift: [100, -100]
      key:
        padding: 1ky
        spread: 1kx
      rotate: main_rot
      columns:
        pinky:
          rows:
            bottom:
              shift: [-4, 0]
              rotate: -90
            home.shift: [-kx, -kx]
            top.shift: [-kx, -kx]
        ring:
          key:
            splay: pinky_splay
            stagger: 13
          rows:
            bottom.shift: [-2, 0]
            top.rotate: 180
        middle:
          key:
            splay: ring_splay
            stagger: 10
          rows.top.rotate: 180
        index.key:
          splay: 0
          stagger: -10
        inner:
          key:
            stagger: -2
          rows:
            home.rotate: 90
            top:
              shift: [kx, -kx]
      rows:
        bottom.padding: kx
        home.padding: kx
        top.padding: kx
    thumb:
      anchor:
        ref: matrix_middle_bottom
        shift: [13, -32]
      columns:
        inner:
          key.name: thumb_inner
        tucky:
          key:
            name: thumb_tucky
            stagger: -2
            splay: -14
            shift: [3, 0]
        reachy:
          key.spread: kx
          key.splay: -16
          key.shift: [7, -1]
          key.rotate: 90
          key.width: thumb_size * kx
          key.name: thumb_reachy
outlines:
  # ==================== keys ====================
  key_outline:
    - what: rectangle
      where: true
      size: [kx, ky]
      operation: stack
  _small_keys:
    - what: rectangle
      where: true
      size: [kx-1, ky-1]
  _expanded_key_outline:
    - what: rectangle
      where: true
      size: [px, py]
  _limits:
    - what: rectangle
      size: [100, 100]
      adjust.shift: [center_x, center_y]
  pcb_outline:
    - what: polygon
      points:
        - shift: [center_x-50, center_y-50+bottom_left_pcb_cut]
        - shift: [0, 100-bottom_left_pcb_cut]
        - shift: [100, 0]
        - shift: [0, -95.25]
        - shift: [-4, -4.75]
        - shift: [-96 + abs(bottom_left_pcb_cut/tan((tot_rot)*pi/180)), 0]
      fillet: 2
  case_outline:
    - what: polygon
      points:
        - shift: [center_x-50-case_left_offset, center_y-50+bottom_left_case_cut]
        - shift: [left_case_x_travel, 100-bottom_left_case_cut+case_tol]
        - shift: [case_left_to_mid_finger_top, case_top_offset]
        - shift: [mid_finger_top_to_case_right_x,mid_finger_top_to_case_right_y]
        - shift: [0, -100-mid_finger_top_to_case_right_y-case_top_offset-case_thumb_y-case_bottom_offset-case_tol]
        - shift: [case_thumb_x, case_thumb_y]
        - shift: [(-100-case_thumb_x-case_left_offset-case_right_offset) +abs((bottom_left_case_cut+case_bottom_offset)/tan((tot_rot)*pi/180)), 0]
      fillet: 3
  _controller_outline:
    - what: polygon
      points:
        - shift: [-17.78, 8.89]
        - shift: [33.02, 0]
        - shift: [0, -17.78]
        - shift: [-33.02, 0]
        - shift: [0, 5.08]
        - shift: [-1.524, 0]
        - shift: [0, 7.62]
        - shift: [1.524, 0]
      adjust:
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

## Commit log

2026-03-14 add footprints submodule
2026-03-15 routed pcb
    [board.kicad_pcb]
2026-04-02 added case, images
2026-04-06 updated list of materials, choc variant
    [board.kicad_pcb]
2026-04-12 added socketing the controller to optional components
